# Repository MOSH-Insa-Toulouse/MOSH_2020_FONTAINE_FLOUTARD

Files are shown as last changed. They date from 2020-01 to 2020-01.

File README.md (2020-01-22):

# MOSH_2020_FONTAINE_FLOUTARD
Source files for the M&OSH project ISS 2019-2020: PCB files, Arduino files and node-red files.

## Table of content

1. [Realisation of the gas sensor](#Realisation-of-the-gas-sensor)
1. [Realisation of the PCB](#Realisation-of-the-PCB)
    1. [Schematic](#schematic)
        1. [Gas sensor](#gas-sensor)
        1. [Amplifier stage](#amplifier-stage)
        1. [Lora Radio](#lora-radio)
        1. [Arduino connection](#arduino-conetion)
    1. [PCB](#pcb)
    1. [3D view](#3d-view)
1. [Arduino code](#arduino-code)
1. [Node Red](#node-red)

# Realisation of the gas sensor

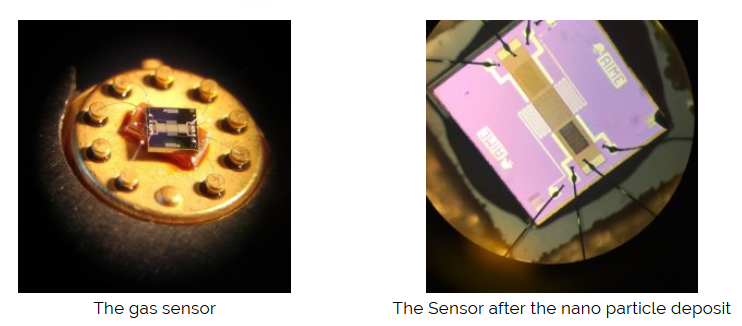
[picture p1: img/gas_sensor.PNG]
Gas Sensor


We realized a gas sensor at the AIME composed of nanoparticles of tungsten. 

The sensor has 10 pins but we do not use all of them.

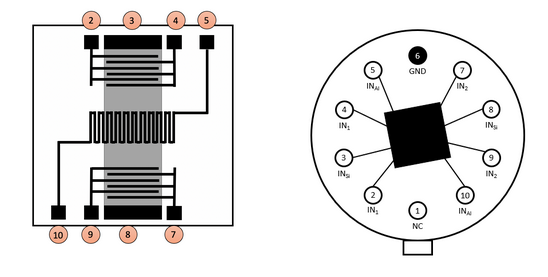
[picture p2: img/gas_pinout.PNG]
Gas Sensor Pinout


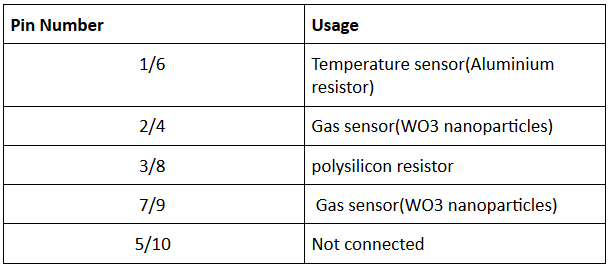
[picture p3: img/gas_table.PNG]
Gas Sensor table


# Realisation of the PCB

## Schematic 

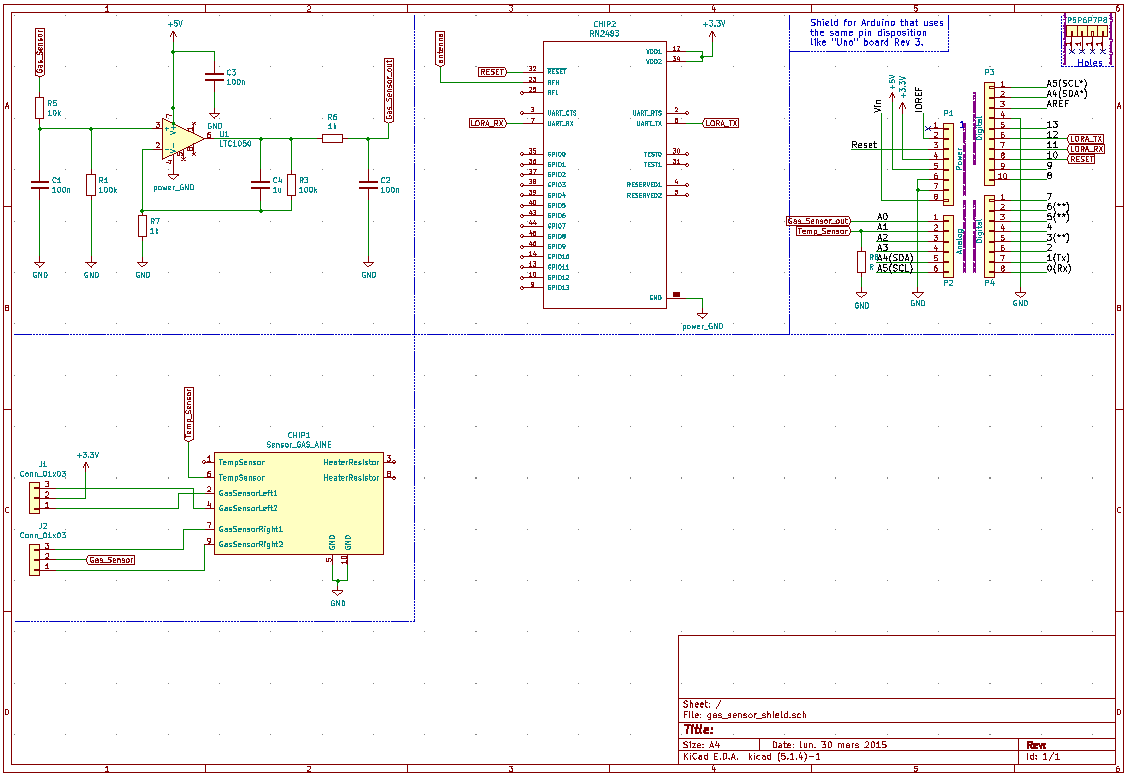
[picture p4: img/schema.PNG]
Schematic


The schematic is composed of 4 parts:

1. The Amplifier stage (on the top-left)
1. The Lora Tx Radio Chip (on the top-middle)
1. The Arduino connection (on the top-right)
1. The Gas sensor connection (on the bottom-left)

### Gas sensor

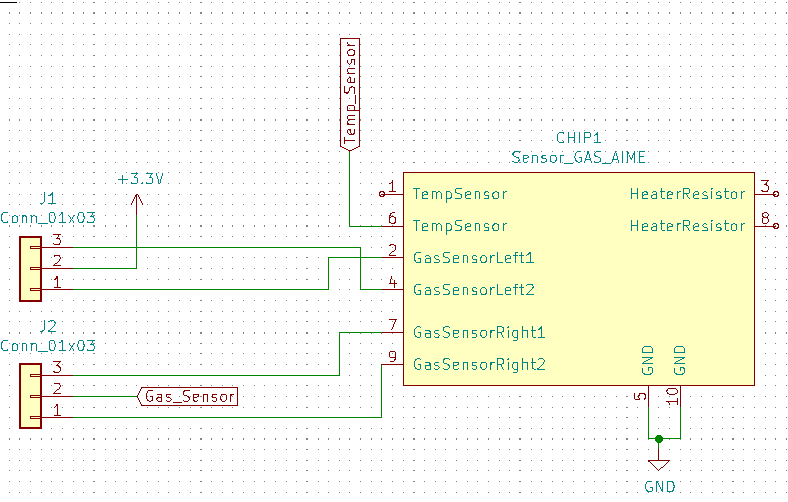
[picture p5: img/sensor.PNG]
Sensor


We connected the output of the gas sensor to two jumpers. So it is easy to switch from one sensor to the other. 

We also connected the temperature output to the Arduino.

### Amplifier stage

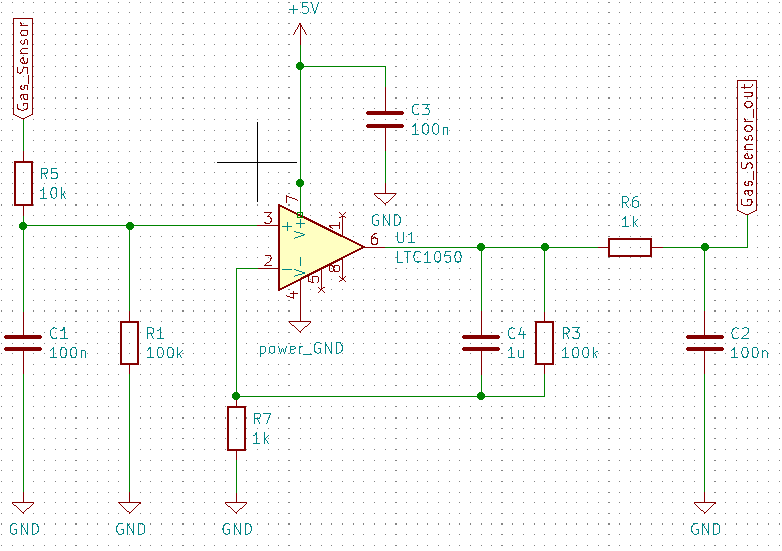
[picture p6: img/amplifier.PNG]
Amplifier


This stage is composed of several filters and an operational amplifier. The role of this stage is to filter and amplify the signal before the analog to digital conversion of the Arduino. 

We used the software LTSpice in order to simulate this analog circuit. This simulator allows us to create all the schematics we want and simulate them with different parameters. For example, we can plot the bode diagram of a circuit in order to find its cut-off frequency.

The first objective was to have an amplification. For this, we use an operational amplifier: the LTC1050. It is a "precision zero-drift" amplifier with a low noise and can be powered by a 5V input. The goal was to have an output of 1.1V for an input of 110nA. As it can be seen on the below screenshot of LTSpice, the goal is achieved.

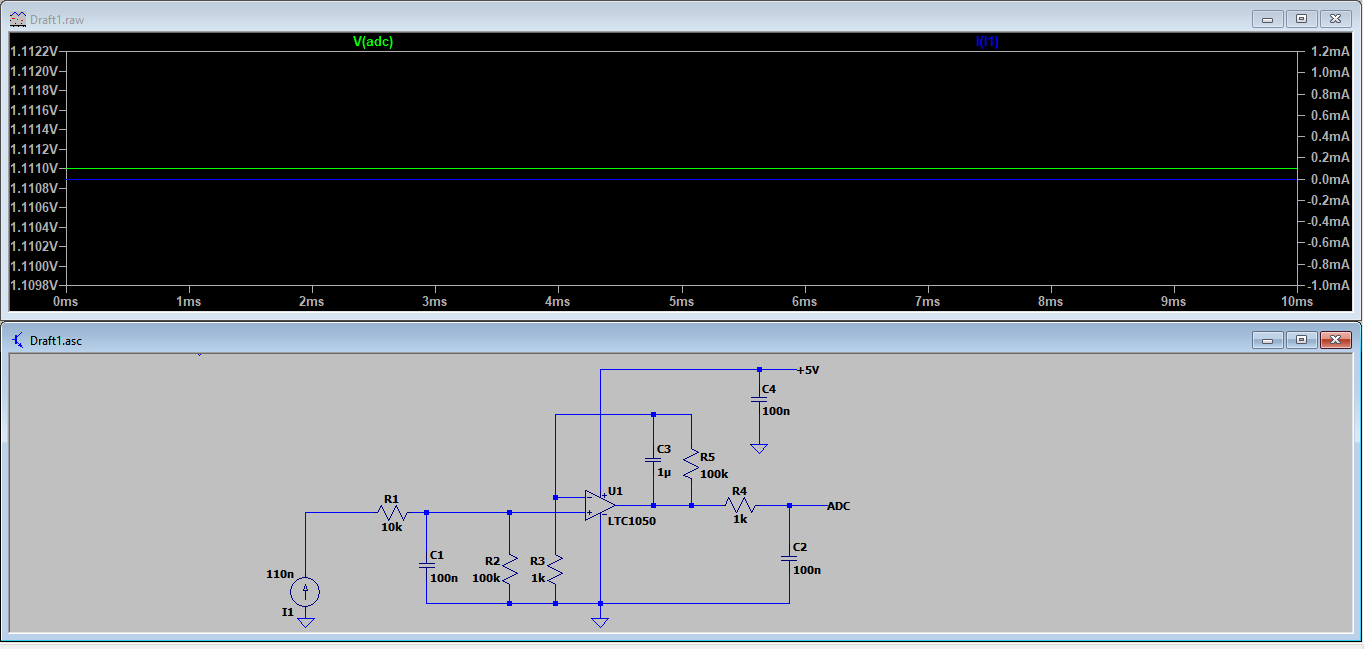
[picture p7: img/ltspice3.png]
LTScpice3


We want to measure the input current in the system. As the input current of an ideal amplifier is null, all the current will go into R2 resistor of 100kΩ. So the input of the amplifier we want to get is the voltage of the R2 resistor. For example, with 110nA, the voltage will be 11mV. And as we want an output of 1.1V, the amplification should be 100.

As the experimental assembly is non-inverting, the gain can be set with R3 and R5 resistors. The gain is 1+R5/R3. So to get a gain of 100, we can choose R5=100kΩ and R3=1kΩ.

The second objective of the system is to filter the signal to reduce the noise. For that, we use 3 different filters. The first one is a simple RC low pass filter with a cut-off frequency of 1/(2\*π\*R1\*C1) an filters the input current. The second filter is an active filter with C3 and R5 which is used with the amplifier and the last filter is a low pass filter with R4 and C2 which filter the output voltage. The C4 capacitor is here to filter the power supply noise.

On the screenshot below, we can see the bode diagram of the circuit.

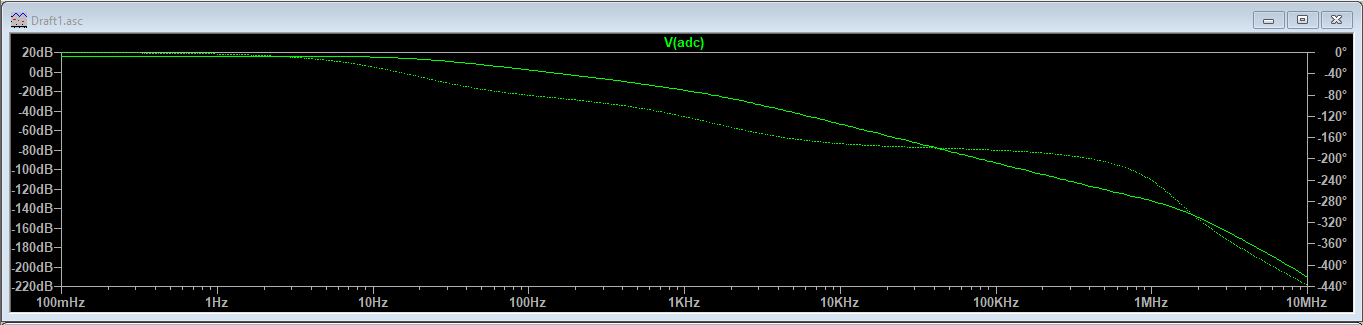
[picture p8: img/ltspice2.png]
LTScpice2


### Lora Radio

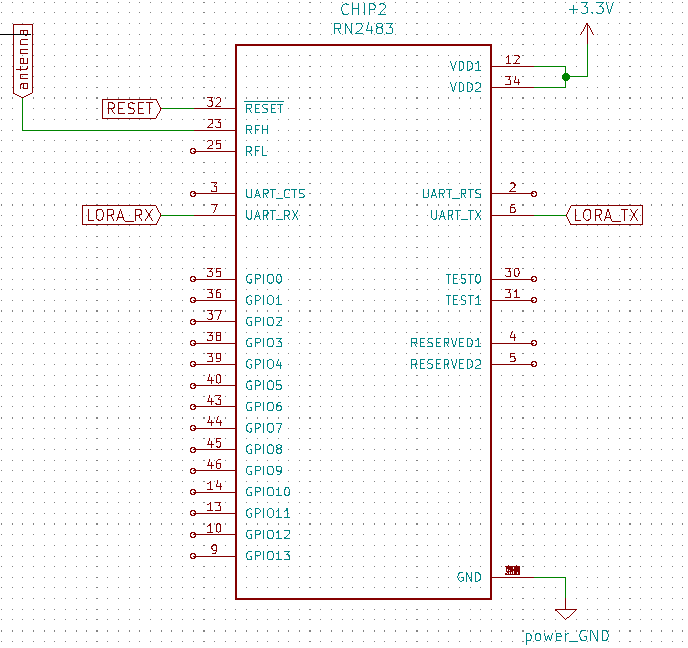
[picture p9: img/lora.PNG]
Lora


We connected only the pin we use on the Lora radio:
* Reset
* RX
* TX
* Antenna
* 3.3 V
* Ground

### Arduino connection

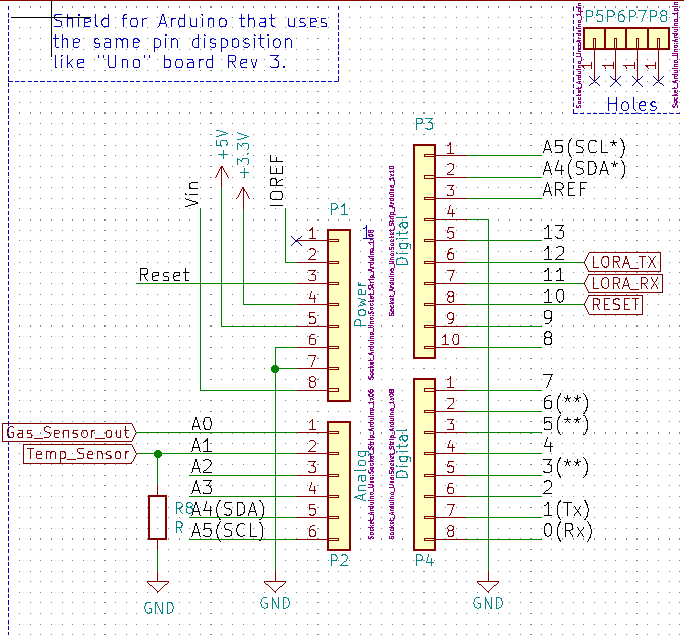
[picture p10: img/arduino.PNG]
Arduino


This schematic was automatically created by Kicad. It is composed of the connector of the shield for the Arduino board.
We connected the following ports:
* Lora TX
* Lora RX
* Reset
* Gas_Sensor_Out
* Temp_Sensor

## PCB

The PCB was designed in order to be simple to realize and to use. 

Main features are the following:
* We can choose the input of the gas sensor by changing jumpers
* The TX Lora radio can be welded directly on the board
* An antenna can be added to the PCB 
* The bottom layer is connected to the ground (green)
* The face layer makes connection between components

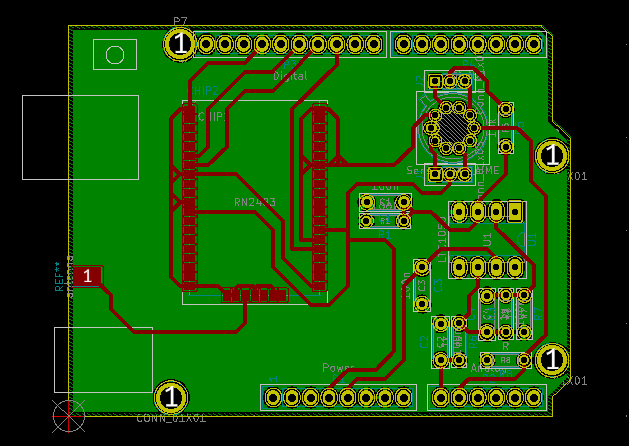
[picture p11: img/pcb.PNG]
PCB


## 3D view

The view in 3D:

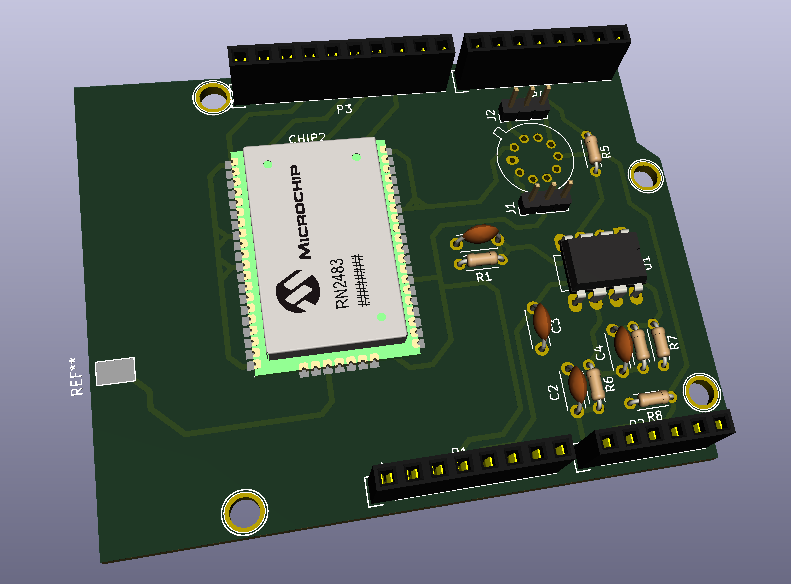
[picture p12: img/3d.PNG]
3D


The source file of the PCB are in the folder [PCB](https://github.com/MOSH-Insa-Toulouse/MOSH_2020_FONTAINE_FLOUTARD/tree/master/PCB)

## Arduino code

The [Arduino source code](https://github.com/MOSH-Insa-Toulouse/MOSH_2020_FONTAINE_FLOUTARD/tree/master/Arduino) is based on the code given by TTN for Lora communication with Arduino. 

The Lora radio sends messages to a TTN gateway. We had to create an account on TTN and add a new project with a new devices.
We chose to use the APB method for connection. 
We created the keys on TTN and added them on the code.

```
const char *devAddr = "26011***";
const char *nwkSKey = "AB82F28D15AC415AA427************";
const char *appSKey = "BA1BF3F2E70ECD142F8*************";

join_result = myLora.initABP(devAddr, appSKey, nwkSKey);
```

We created two different codes:

* *Send the gas sensor value*

In order to read the value from the gas sensor, we used `analogRead()`. We sent the value with the Lora radio.

* *Send an alert when value is too high*

We also implemented a code which sends an alert if the value from the gas sensor is too high. This code uses an interrupt attached to pin 2. 

## Node Red

The last part of our project was to retrieve data from TTN on Node red. 

We use the TTN node red library:

NodeRed

We fill the TTN block with the correct data from TTN:

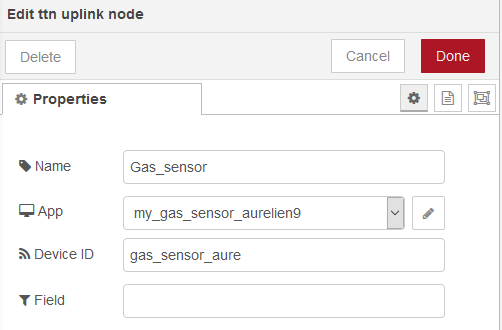
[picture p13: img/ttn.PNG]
TTN


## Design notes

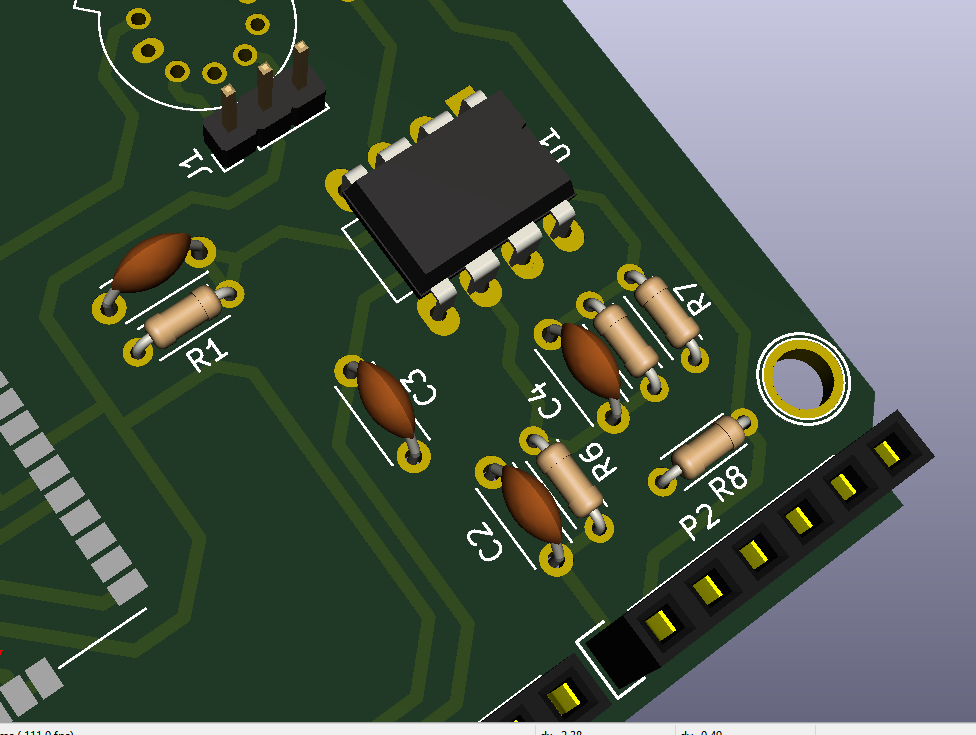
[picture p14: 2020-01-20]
img/amp_d.PNG

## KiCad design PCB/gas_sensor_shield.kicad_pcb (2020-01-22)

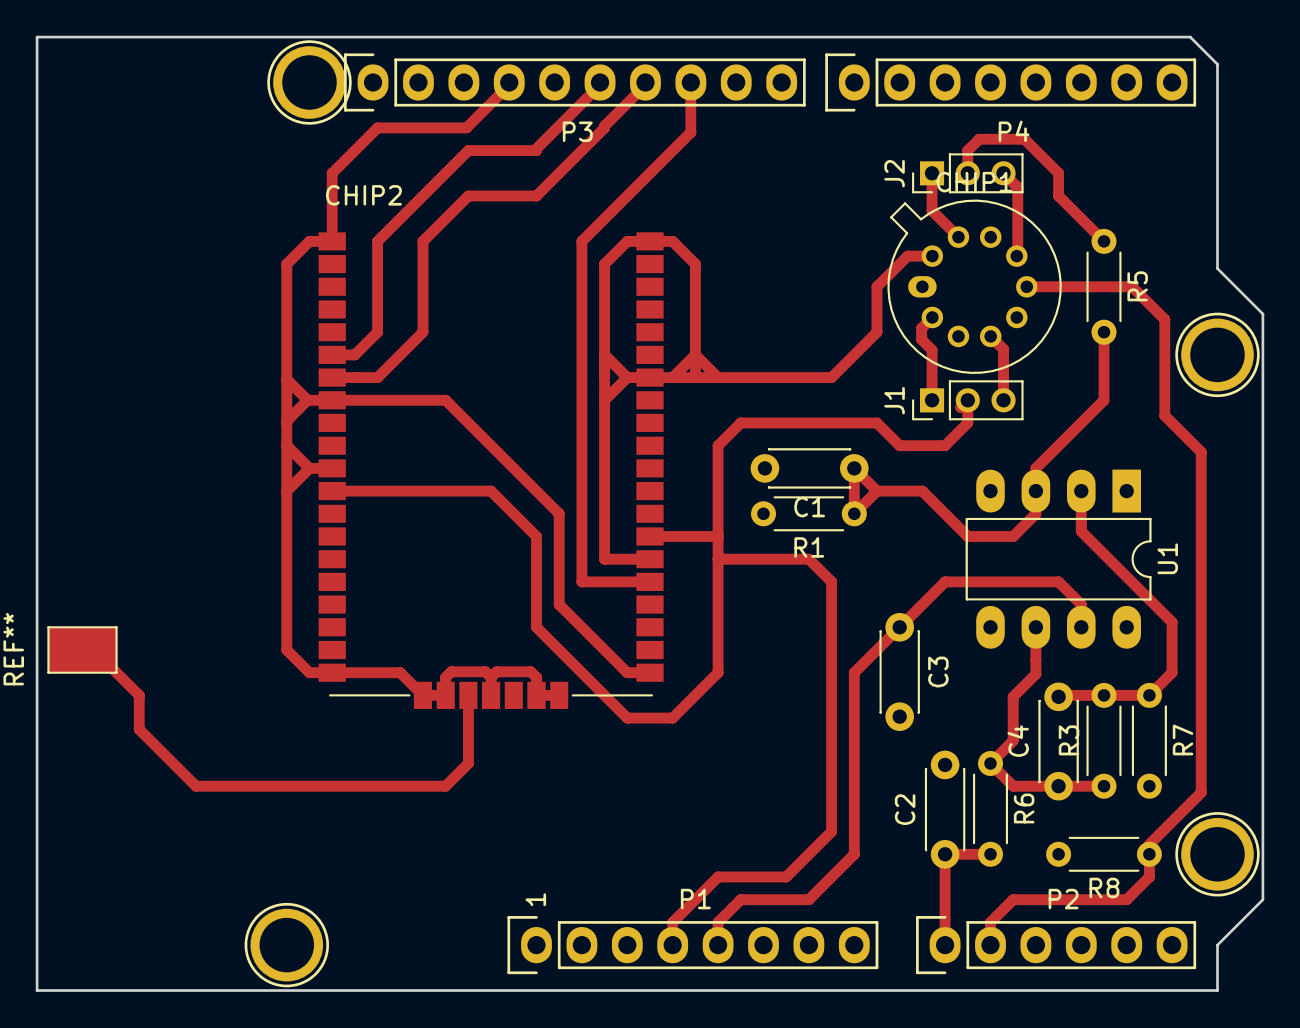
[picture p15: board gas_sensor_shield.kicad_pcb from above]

Board: 2 copper layers, 68.6 x 53.3 mm, 23 parts (0 on the bottom side), 16 nets.

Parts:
C1, C2, C3: 100n; C_Disc_D4.3mm_W1.9mm_P5.00mm
C4: 1u; C_Disc_D4.3mm_W1.9mm_P5.00mm
CHIP1: Sensor_GAS_AIME; TO-5-10_Window
CHIP2: RN2483
J1, J2: Conn_01x03; PinHeader_1x03_P2.00mm_Vertical
P1: Power; Socket_Strip_Arduino_1x08
P2: Analog; Socket_Strip_Arduino_1x06
P3: Digital; Socket_Strip_Arduino_1x10
P4: Digital; Socket_Strip_Arduino_1x08
P5, P6, P7, P8: CONN_01X01; Arduino_1pin
R1, R3: 100k; R_Axial_DIN0204_L3.6mm_D1.6mm_P5.08mm_Horizontal
R5: 10k; R_Axial_DIN0204_L3.6mm_D1.6mm_P5.08mm_Horizontal
R6, R7: 1k; R_Axial_DIN0204_L3.6mm_D1.6mm_P5.08mm_Horizontal
R8: R; R_Axial_DIN0204_L3.6mm_D1.6mm_P5.08mm_Horizontal
U1: LTC1050; DIP-8_W7.62mm_LongPads

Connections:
+3V3: CHIP2.12, CHIP2.34, J1.2, P1.4
+5V: C3.1, P1.5, U1.7
GND: C1.2, C2.2, C3.2, CHIP1.5, CHIP1.10, CHIP2.1, CHIP2.8, CHIP2.11, CHIP2.20, CHIP2.21, CHIP2.22, CHIP2.24, CHIP2.26, CHIP2.27, CHIP2.28, CHIP2.33, CHIP2.41, CHIP2.47, P1.6, P1.7, P3.4, R1.2, R7.2, R8.2, U1.4
Gas_Sensor: J2.2, R5.1
Gas_Sensor_out: C2.1, P2.1, R6.2
LORA_RX: CHIP2.7, P3.7
LORA_TX: CHIP2.6, P3.6
unnamed: C1.1, R1.1, R5.2, U1.3
unnamed: C4.1, R3.1, R6.1, U1.6
unnamed: C4.2, R3.2, R7.1, U1.2
unnamed: CHIP1.2, J1.1
unnamed: CHIP1.4, J1.3
unnamed: CHIP1.7, J2.3
unnamed: CHIP1.9, J2.1
RESET: CHIP2.32, P3.8
Temp_Sensor: CHIP1.6, P2.2, R8.1

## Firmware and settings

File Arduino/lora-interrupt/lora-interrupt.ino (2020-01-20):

/*
 * Author: JP Meijers
 * Date: 2016-02-07
 * Previous filename: TTN-Mapper-TTNEnschede-V1
 *
 * This program is meant to be used with an Arduino UNO or NANO, conencted to an RNxx3 radio module.
 * It will most likely also work on other compatible Arduino or Arduino compatible boards, like The Things Uno, but might need some slight modifications.
 *
 * Transmit a one byte packet via TTN. This happens as fast as possible, while still keeping to
 * the 1% duty cycle rules enforced by the RN2483's built in LoRaWAN stack. Even though this is
 * allowed by the radio regulations of the 868MHz band, the fair use policy of TTN may prohibit this.
 *
 * CHECK THE RULES BEFORE USING THIS PROGRAM!
 *
 * CHANGE ADDRESS!
 * Change the device address, network (session) key, and app (session) key to the values
 * that are registered via the TTN dashboard.
 * The appropriate line is "myLora.initABP(XXX);" or "myLora.initOTAA(XXX);"
 * When using ABP, it is advised to enable "relax frame count".
 *
 * Connect the RN2xx3 as follows:
 * RN2xx3 -- Arduino
 * Uart TX -- 10
 * Uart RX -- 11
 * Reset -- 12
 * Vcc -- 3.3V
 * Gnd -- Gnd
 *
 * If you use an Arduino with a free hardware serial port, you can replace
 * the line "rn2xx3 myLora(mySerial);"
 * with     "rn2xx3 myLora(SerialX);"
 * where the parameter is the serial port the RN2xx3 is connected to.
 * Remember that the serial port should be initialised before calling initTTN().
 * For best performance the serial port should be set to 57600 baud, which is impossible with a software serial port.
 * If you use 57600 baud, you can remove the line "myLora.autobaud();".
 *
 */
#include <rn2xx3.h>
#include <SoftwareSerial.h>
#include <avr/sleep.h>
#include <avr/power.h>

SoftwareSerial mySerial(10, 11); // RX, TX

//create an instance of the rn2xx3 library,
//giving the software serial as port to use
rn2xx3 myLora(mySerial);


int pin2 = 2;

// the setup routine runs once when you press reset:
void setup()
{
  //output LED pin
  pinMode(13, OUTPUT);
  led_on();

  pinMode(pin2, INPUT_PULLUP);
  
  // Open serial communications and wait for port to open:
  Serial.begin(57600); //serial port to computer
  mySerial.begin(9600); //serial port to radio
  Serial.println("Startup");

  initialize_radio();

  attachInterrupt(digitalPinToInterrupt(pin2), pin2Interrupt, LOW);


  //transmit a startup message
  myLora.tx("TTN Mapper on TTN Enschede node");

  led_off();
  delay(2000);
}

void initialize_radio()
{
  //reset rn2483
  pinMode(12, OUTPUT);
  digitalWrite(12, LOW);
  delay(500);
  digitalWrite(12, HIGH);

  delay(100); //wait for the RN2xx3's startup message
  mySerial.flush();

  //Autobaud the rn2483 module to 9600. The default would otherwise be 57600.
  myLora.autobaud();

  //check communication with radio
  String hweui = myLora.hweui();
  while(hweui.length() != 16)
  {
    Serial.println("Communication with RN2xx3 unsuccessful. Power cycle the board.");
    Serial.println(hweui);
    delay(10000);
    hweui = myLora.hweui();
  }

  //print out the HWEUI so that we can register it via ttnctl
  Serial.println("When using OTAA, register this DevEUI: ");
  Serial.println(myLora.hweui());
  Serial.println("RN2xx3 firmware version:");
  Serial.println(myLora.sysver());

  //configure your keys and join the network
  Serial.println("Trying to join TTN");
  bool join_result = false;


  /*
   * ABP: initABP(String addr, String AppSKey, String NwkSKey);
   * Paste the example code from the TTN console here:
   */
  const char *devAddr = "2601171F";
  const char *nwkSKey = "AB82F28D15AC415AA4278D941D0FD55C";
  const char *appSKey = "BA1BF3F2E70ECD142F88E88E2300285B";

  join_result = myLora.initABP(devAddr, appSKey, nwkSKey);

  /*
   * OTAA: initOTAA(String AppEUI, String AppKey);
   * If you are using OTAA, paste the example code from the TTN console here:
   */
//  const char *appEui = "70B3D57ED0025B21";
  //const char *appKey = "85D5DC42E7400120FA9A5B7C29B04C07";

  //join_result = myLora.initOTAA(appEui, appKey);


  while(!join_result)
  {
    Serial.println("Unable to join. Are your keys correct, and do you have TTN coverage?");
    delay(60000); //delay a minute before retry
    join_result = myLora.init();
  }
  Serial.println("Successfully joined TTN");

}

int seconds=0;
// the loop routine runs over and over again forever:
void loop()
{ 
    Serial.println("Entering sleep mode");
    enterSleep();
    
    led_on();

    Serial.println("TXing");
    myLora.tx("!"); //one byte, blocking function

    led_off();
    delay(100);
}

void led_on()
{
  digitalWrite(13, 1);
}

void led_off()
{
  digitalWrite(13, 0);
}

void enterSleep(void)
{
  
  /* Setup pin2 as an interrupt and attach handler. */
  delay(100);
  
  set_sleep_mode(SLEEP_MODE_PWR_DOWN);
  
  sleep_enable();
  
  sleep_mode();
  
  /* The program will continue from here. */
  
  /* First thing to do is disable sleep. */
  sleep_disable(); 
}


void pin2Interrupt(void)
{
  /* This will bring us back from sleep. */
  
  /* We detach the interrupt to stop it from 
   * continuously firing while the interrupt pin
   * is low.
   */
  Serial.println("Interrupt");
  //detachInterrupt(digitalPinToInterrupt(pin2));
}

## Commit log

2020-01-18 Add pcb files
2020-01-18 add img and arduino
2020-01-18 Add arduino
2020-01-22 add aime
    [gas_sensor_shield.kicad_pcb]
